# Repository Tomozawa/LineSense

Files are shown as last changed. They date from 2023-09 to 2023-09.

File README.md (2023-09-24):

# LineSense
NHK24用ラインセンサ基板。BOMは[こちら](https://docs.google.com/spreadsheets/d/12akROPWRgP_KYzk62EP3h0m6oYP8IBUy/edit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)

## バージョン履歴
### ver2.0
12V改良版

## 概要
地面の色(水性塗料でペイントされている)を判別することができるセンサ。白かそれ以外(青、緑、オレンジ、黄、赤のいずれか)かを判別する。地面の下が白色である確率に応じた振幅の正弦波(200&#126;2kHz)がSIG_OUTから出力される。出力された信号を包括線検波することで反射率を取得できる。LEDを200&#126;2kHzで点滅させることで光の反射率をAM変調し、光学フィルタでLEDの波長以外をカットし、ローパスフィルタとカップリングで照明の信号をカットしているため、比較的地面と離れていても実用に耐えられるよう配慮している。これは、センサの位置を高めにすることでフィールドにある傾斜の影響を極力小さくするためである。

## 基板の作り方(推奨)
部品の温度特性を考慮して、未使用時でも3カ月に1回は校正を行うこと。また、実運用時には機械的な振動で半固定抵抗がずれるため、機体を起動させる際に攻勢を行うこと。

### 1. LED点灯回路を組む
Sheet 2/2 の部品を取り付け、CN1に仮の電線をつけ、LEDが点灯することを確認する。また、TP1(テストポイント)から200~2kHzの矩形波が観測されるか確認する。

### 2. 受光回路を組む
Q1, R1, R10, C5を取り付け、白い紙に反射させたLED光に反応することを確認する(200~2kHzの波が確認できるはず)。出力波形はTP2(生信号)またはTP3(カップリング済み信号)で確認できる。信号が弱い場合はR10を時計回りに回すことでゲインを上げる。

### 3. プリアンプ/フィルタ/アンプを組む
残りの部品を取り付け、白い紙に反射させたLED光に反応することを確認する。出力波形はTP5またはコネクタから取ってくる。信号が弱い場合はR5を時計回りに回すことでプリアンプのゲインを上げる。

### 4. 光学フィルタをつける
光センサ(Q1)を20mm平方の青いセロハンで覆う。

### 5. 校正を行う
以下のセクションで説明のある方法で校正を行う。

## 校正の仕方
周囲の照明を出来る限り本番の状況に合わせ、白い紙にセンサを水平に設置して行う。この時の紙との距離は、機体のセンサを搭載した時の高さに合わせる。

### 受光回路の感度の校正
R10を調整しながら周囲の照明による直流成分が4V以下になるようにする。センサの出力はTP2を確認する。R10を時計回りに回すと感度が高くなり、反時計回りに回すと小さくなる。

### LEDの点滅周波数の校正
TP1にオシロスコープのプローブを当て、R16を調整しながらTP1から1kHzの矩形波が出力されるようにする。R16を時計回りに回すと周波数が上がり、反時計回りに回すと周波数が下がる。この時、TP3の信号の振幅が100mVp-pを下回った場合、周波数を落として振幅が100mVp-p以上になるようにする。

### プリアンプのゲインの校正
受光回路のゲイン校正と同様の条件に加え、SIG_OUTに36Ωの負荷抵抗を接続した状態で、R5を調整しながらTP5で出てくる信号が歪まないギリギリまでゲインを上げる。TP5の信号の頂点の部分(約3.0V~3.3V程度)が歪まない(つぶれない)限界までR5を時計回りに回す。

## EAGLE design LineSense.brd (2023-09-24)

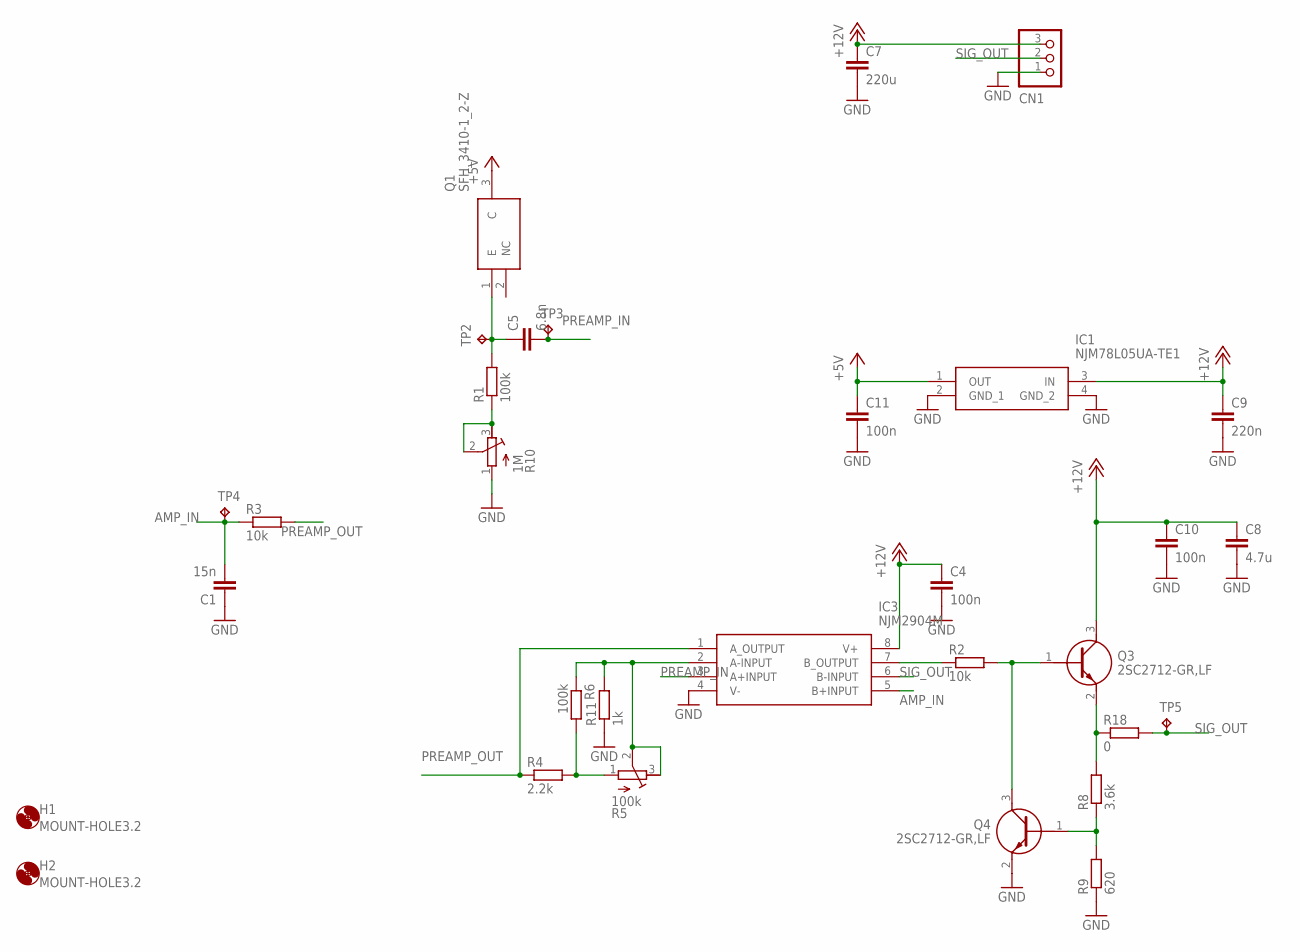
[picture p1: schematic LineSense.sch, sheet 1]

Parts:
C1: 15n; C0603
C4, C10, C11: 100n; C0603
C5: 6.8n; C0603
C7: 220u; C025-025X050
C8: 4.7u; C1210
C9: 220n; C0603
CN1: S3B-XH-A
H1, H2: MOUNT-HOLE3.2; 3,2
IC1: NJM78L05UA-TE1; SOT-89-3
IC3: NJM2904M; SOIC127P680X200-8N
Q1: SFH_3410-1_2-Z; SFH341012Z
Q3, Q4: 2SC2712-GR,LF; SSM3J334RLF
R1, R6: 100k; R0603
R2, R3: 10k; R0603
R4: 2.2k; R0603
R5: 100k; RTRIM3339P
R8: 3.6k; R0603
R9: 620; R0603
R10: 1M; RTRIM3339P
R11: 1k; R0603
R18: 0; R0603
TP2, TP3, TP4, TP5: TPB1,27; B1,27

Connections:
+5V: C11.1, IC1.1 (OUT), Q1.3 (C)
+12V: C4.1, C7.1, C8.1, C9.1, C10.1, CN1.3, IC1.3 (IN), IC3.8 (V+), Q3.3 (C); also elsewhere on the board
AMP_IN: C1.2, IC3.5 (B+INPUT), R3.1, TP4.TP
GND: C1.1, C4.2, C7.2, C8.2, C9.2, C10.2, C11.2, CN1.1, IC1.2 (GND_1), IC1.4 (GND_2), IC3.4 (V-), Q4.2 (E), R9.1, R10.1 (A), R11.1; also elsewhere on the board
unnamed: R1.1, R10.2 (S), R10.3 (E)
unnamed: Q3.2 (E), R8.2, R18.1
unnamed: C5.1, Q1.1 (E), R1.2, TP2.TP
unnamed: R4.2, R5.1 (A), R6.2
unnamed: IC3.2 (A-INPUT), R5.2 (S), R5.3 (E), R6.1, R11.2
unnamed: IC3.7 (B_OUTPUT), R2.1
unnamed: Q3.1 (B), Q4.3 (C), R2.2
unnamed: Q4.1 (B), R8.1, R9.2
PREAMP_IN: C5.2, IC3.3 (A+INPUT), TP3.TP
PREAMP_OUT: IC3.1 (A_OUTPUT), R3.2, R4.1
SIG_OUT: CN1.2, IC3.6 (B-INPUT), R18.2, TP5.TP

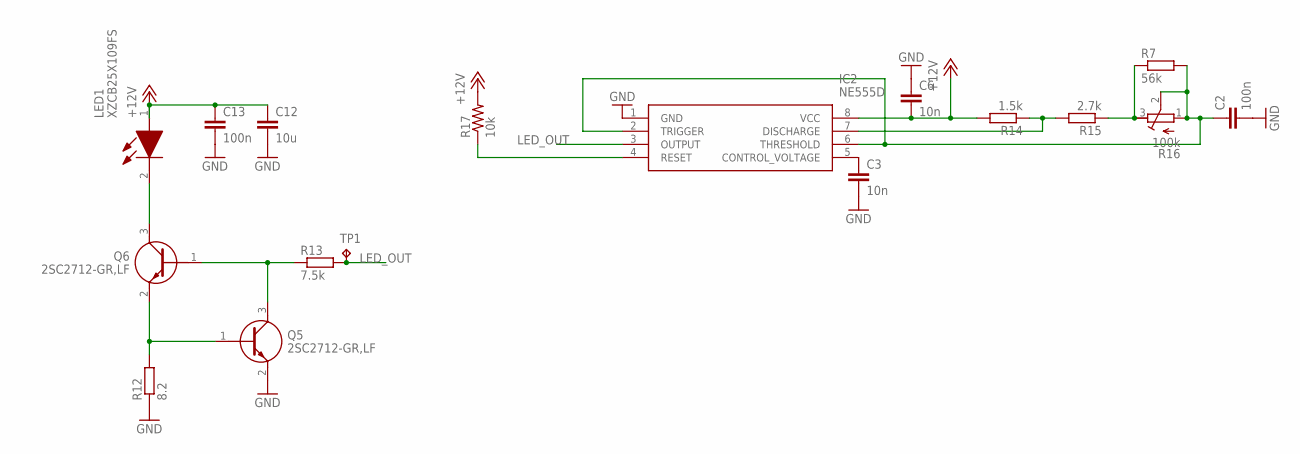
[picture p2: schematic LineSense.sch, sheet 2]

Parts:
C2, C13: 100n; C0603
C3, C6: 10n; C0603
C12: 10u; C1210
IC2: NE555D; SOIC127P600X200-8N
LED1: XZCB25X109FS
Q5, Q6: 2SC2712-GR,LF; SSM3J334RLF
R7: 56k; R0603
R12: 8.2; R0603
R13: 7.5k; R0603
R14: 1.5k; R0603
R15: 2.7k; R0603
R16: 100k; RTRIM3339P
R17: 10k; R0603
TP1: TPB1,27; B1,27

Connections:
+12V: C6.2, C12.1, C13.1, IC2.8 (VCC), LED1.1 (A), R14.2, R17.2; also elsewhere on the board
GND: C2.2, C3.2, C6.1, C12.2, C13.2, IC2.1 (GND), Q5.2 (E), R12.1; also elsewhere on the board
LED_OUT: IC2.3 (OUTPUT), R13.2, TP1.TP
unnamed: LED1.2 (K), Q6.3 (C)
unnamed: Q5.1 (B), Q6.2 (E), R12.2
unnamed: Q5.3 (C), Q6.1 (B), R13.1
unnamed: C3.1, IC2.5 (CONTROL_VOLTAGE)
unnamed: IC2.4 (RESET), R17.1
unnamed: C2.1, IC2.2 (TRIGGER), IC2.6 (THRESHOLD), R7.2, R16.1 (A), R16.2 (S)
unnamed: IC2.7 (DISCHARGE), R14.1, R15.2
unnamed: R7.1, R15.1, R16.3 (E)

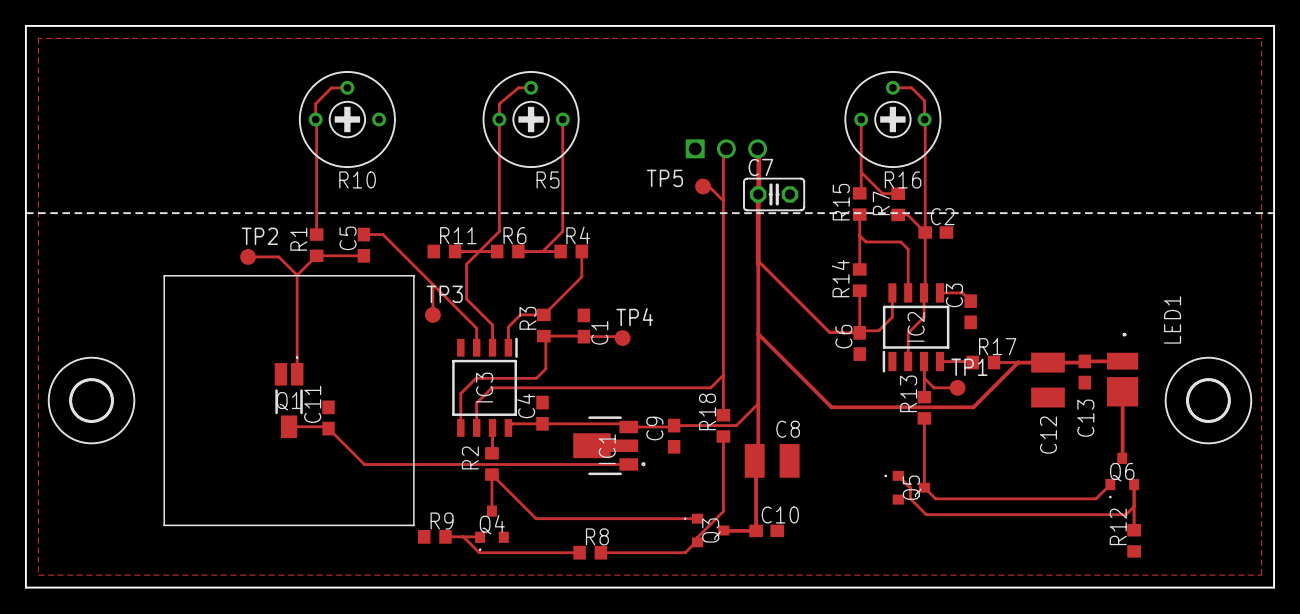
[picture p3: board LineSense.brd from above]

Board: 2 copper layers, 100.0 x 45.0 mm, 48 parts (1 on the bottom side), 24 nets.

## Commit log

2023-09-09 BOM info
2023-09-16 Revert "BOM info"
    This reverts commit b7451d02ac79e986c6a60497e87a7443eaa3fbfb.
2023-09-16 Revert "Revert "BOM info""
    This reverts commit 3cd070827710dd9a6509c16180cd1ad1550c4722.
2023-09-16 Revert "v1.2"
    This reverts commit 20100e136a2bdf049fa62e188f43b768e8603774.
    [LineSense.brd, LineSense.sch]
2023-09-24 The First ver2.x
    [LineSense.brd, LineSense.sch]
2023-09-24 Update load resistance of reciever
    [LineSense.brd, LineSense.sch]
